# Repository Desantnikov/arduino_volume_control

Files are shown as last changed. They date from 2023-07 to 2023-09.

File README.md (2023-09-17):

<h1>Touchless PC volume controller arduino project.</h1>
<h2>
No need to touch stuff anymore. Adjust volume just by swinging your hand. 
</h2>

Basically you just place your hand inside this box and swing it up and down. And volume 
is changes according to your hand's Y position.  
Volume control and media play/pause will work only on windows 

<pre>
_____-
|
|
|
|
|
|
|
|
—   --
| ^  |
| 1* |
——----
</pre>

`1*` - distance sensor with measurement direction marked by ^ 

Main idea is to place a distance sensor inside the box. Distance sensor should 
be fixed on the bottom of the box. Distance measurements should be directed from box bottom to box top. 
Measurements happen several times per second. 
If currently measured distance equals to overall box height - it means that there
are no obstacles between the bottom and the top. But if measured distance is less than overall box 
height - it means that something is present in the box. And using measured distance we know it's
exact position on the Y coord. Then measurements values are sent to PC to adjust volume accordingly  

<h1>Version 1</h1> 
<h2>
Uses firmata protocol to fully control arduino from PC. 
No arduino code, all measurement values go directly to python script 
</h2> 

Sketch from examples of FirmataExpress arduino lib is uploaded on arduino. It fully implements firmata protocol
and gives ability to do all the shit you would want to do inside the arduino sketch. Allows not only setting 
pins HIGH or LOW, but also provides handy wrappers for many types of detectors. Everything is good 
except wired connection necessity.
Don't forget to set correct pins in the `/v1/constants.py`

Components used:
- Arduino nano
- US-015 ultrasonic distance sensor
<hr>

<h1>Version 2</h1>
<h2>
Uses better distance sensor and bluetooth module to send measurement results.
</h2>

Uses better distance sensor US-100, which supports UART mode and accepts commands instead
of setting and reading pins voltage directly. Also it has a built-in thermometer, which is not used in this
project. After first tests I could say that it works better than US-015.
Uses ZS-040 bluetooth module to send measurement results. Please note that before connecting it has to be
switched to the AT mode. To check if it's switched - open serial terminal and type "AT". And don't forget to set 
both CR and LF endlines. Official doc says that default connection password is "000000". In my case it was "1234".
All baudrates should be 9600, but in case of any issues you might try 38400.
Usually ZS-040 has a 'HC-06' bluetooth name.
Your PC should be paired with it to use it as a regular serial device using 'Serial over Bluetooth'.  

SW_520D tilt-switch sensor is used to track when user hit the controller. And if hit two 
times - plays/pauses what is currently playing
Curcuits schema can be found in /v2/circuits, `*.fxx` is a Fritzing applications format. Have much more 
components (like US-100 or ZA-40) than tinkercad, circuitIO and other webapp shit.   
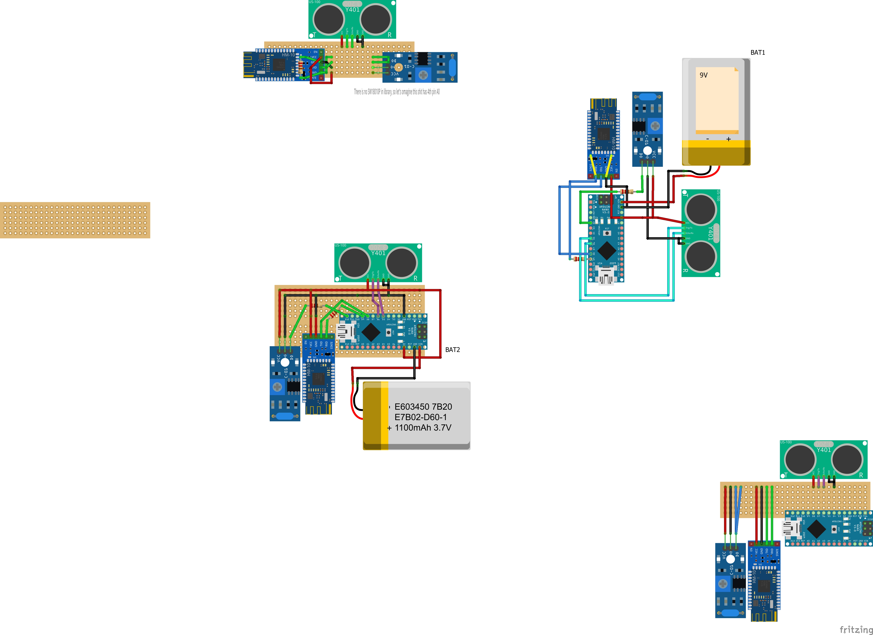
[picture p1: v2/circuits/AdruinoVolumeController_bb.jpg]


Lots of workarounds were used in python code and in arduino sketch. But these workarounds really improved 
the measurement process and made controlling PC with this stuff more or less smooth.

Python W/A's
1. When processing data from distance sensor - ignore fluctuations of less than 5% of volume
2. When registering doubleclick with vibration sensor 
   3. ignore vibros if they happened right after previous vibro - 
      usually that happens when sensor is not placed properly or instead of clicks user makes long pushes
   4. ignore doubleclick if second vibro happened too late after first vibro  
   5. ignore doubleclick if it happened too early after previous - same as 3th point

Similiar workarounds were made on the Arduino side.
Main question here is how this all will work when soldered. Maybe more workarounds will be needed. Or to rework 
using vibro sensor to read pin in a main loop instead of using interruptions

Components used:
- Arduino nano
- US-100 ultrasonic distance sensor
- ZS-040 bluetooth module
- SW18010P vibration sensor (initially took SW-520D, but I don't need a tilt sensor)
- 9v battery (to be replaced with 5v power supply, distance sensor goes crazy when 9v applied)

<h1>Version 2.1</h1>
<h3>
I have burnt ST_18010P vibro sensor during soldering and don't want to wait for a new one, so 
returning back to SW-520D vibration sensors.
</h3>
<p>
While ST_18010P was able to return both digital and analogue values, SW-520D   
</p>

Here is basic SW-520D connection circuit.
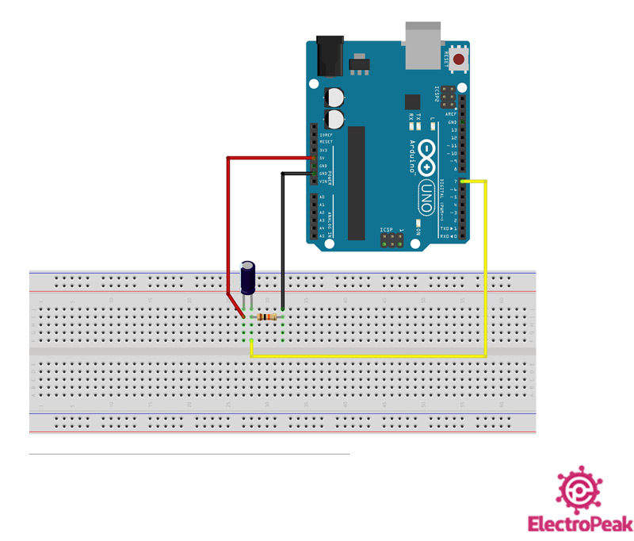
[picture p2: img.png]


Also analog reading when arduino is powered via USB from PC sucks. So currently 
I'll use only digital pins and postpone analog reading. Anyway, when powered from PC, 
it always returns either 800 or 0.  

Empirically I found out that if several such sensors are connected in 
parralel - they work like an OR clause.  You will have True (no vibration) when at
least one sensor returns true. 
When reading analog - you will have the biggest value from all sensors.
(it returns 0 when sensor is upside-down and 1023 when it's 
staying straight without movement).

And using several sensors at once helps to filter fake-positive cases. For example
when you make one tap - something about 15-20 events are triggered, and if you use 
interruptions then you have to make workarounds. Or sometimes you just have 
random fake-positive events.
On the other side, adding just one more sensor fixed problem with 15 events for one 
tap. And now double-tap could be caught almost perfectly and without any 
filtering/thresholds and other stuff.

<h1>Making and *.exe file</h1>
* make sure you have installed microsoft visual c++ 2015
* make sure you have installed gevent package
* execute `auto-py-to-exe`

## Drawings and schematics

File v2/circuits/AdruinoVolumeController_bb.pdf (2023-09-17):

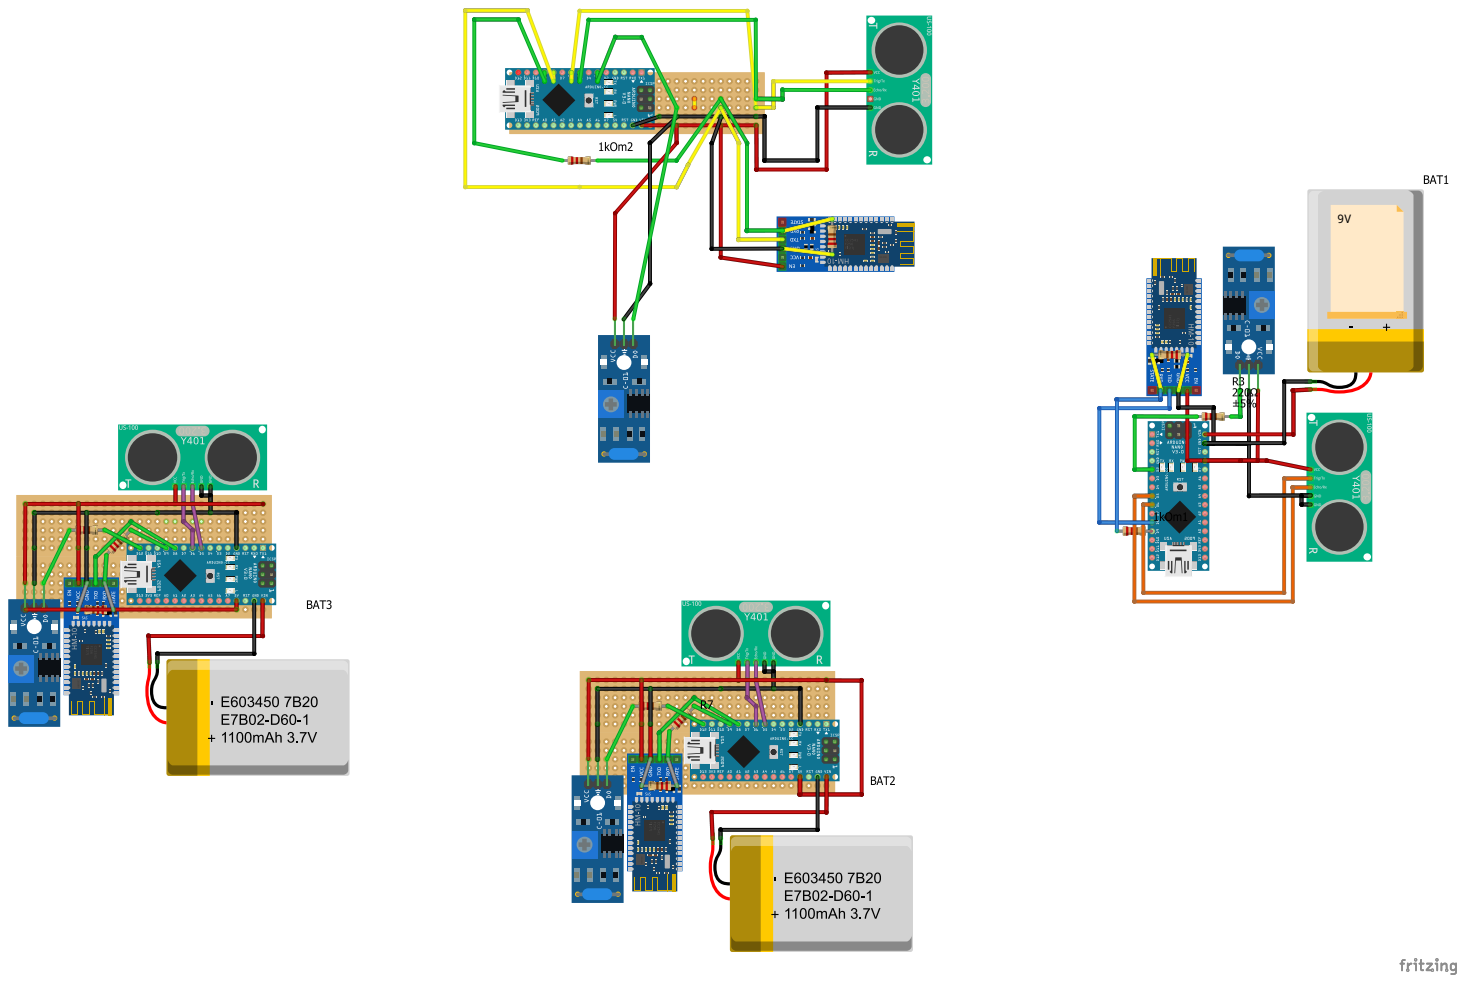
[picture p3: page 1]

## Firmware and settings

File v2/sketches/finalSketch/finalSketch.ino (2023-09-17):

#include <SoftwareSerial.h>;

// ultrasonic distance detector
const int US100_TX = 4;
const int US100_RX = 3;

// bluetooth module
const int ZS040_TX = 6;
const int ZS040_RX = 5;

//SW_520D vibration Sensor
//const int SW_520D_ANALOG_INPUT = A7;
const int SW_520D_DIGITAL_INPUT = 2;

int vibroSensorValue = 0;

SoftwareSerial detectorUS100(US100_RX, US100_TX);
SoftwareSerial bluetoothZS040(ZS040_RX, ZS040_TX);

unsigned int distanceRawFirstByte = 0;
unsigned int distanceRawSecondByte = 0;

unsigned int distanceMillimeters = 0, previousDistanceMillimeters = 0;

// function sends string via BT module byte by byte
void sendStringBluetooth(String stringToSend) {
  Serial.print("Sending data via BT: " + stringToSend + "\r\n");

  for (int i = 0; i < stringToSend.length(); i++) {
    bluetoothZS040.write(stringToSend[i]);
  }
  // delay(30);
}

int getDistance() {  // to measure distance in UART mode it's needed to:
    detectorUS100.flush();  // clear buffer
    detectorUS100.write(0x55);  // send command to measure distance

    delay(50);  // setting lower than 100 cause shitty measurements

    distanceRawFirstByte = detectorUS100.read();
    distanceRawSecondByte  = detectorUS100.read();

    distanceMillimeters = distanceRawFirstByte * 256 + distanceRawSecondByte;

    return distanceMillimeters;
}

void processDistance(int distanceMillimeters, int previousDistanceMillimeters) {
    // Serial.print("Distance: ");
    // Serial.print(distanceMillimeters);
    if (distanceMillimeters == previousDistanceMillimeters)
    {
// //
      // Serial.print("; Difference is less than 5 millimeters, ignore \r\n");
      return;
    }

    if((distanceMillimeters > 45) && (distanceMillimeters < 350))  // limits should align with limits from constants.py
    {
      sendStringBluetooth("Distance: " + String(distanceMillimeters) + "\r\n");
    }

}

void setup() {
 Serial.begin(9600);
 Serial.write("STARTED");

  bluetoothZS040.begin(9600);  // BT module
  detectorUS100.begin(9600);  // distance
  
  // pinMode(SW_18010P_ANALOG, INPUT);  // vibro
 pinMode(SW_520D_DIGITAL_INPUT, INPUT);  // vibro
}

void loop()
{

  vibroSensorValue = digitalRead(SW_520D_DIGITAL_INPUT);
// averageVibroSensorValue

   if (vibroSensorValue == LOW) {
    // if (vibroSensorValue == 0) {
      Serial.println("Vibro sensor triggered");
       sendStringBluetooth("Vibro: " + String(vibroSensorValue) + "\r\n");
     }
   delay(50);
  // }
  
  
 previousDistanceMillimeters = distanceMillimeters;
 distanceMillimeters = getDistance();
//
  processDistance(distanceMillimeters, previousDistanceMillimeters);

}

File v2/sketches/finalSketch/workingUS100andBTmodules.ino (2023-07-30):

#include <SoftwareSerial.h>;

// ultrasonic distance detector
const int US100_TX = 2;
const int US100_RX = 3;

// bluetooth module
const int ZS040_TX = 9;
const int ZS040_RX = 8;

SoftwareSerial detectorUS100(US100_RX, US100_TX);
SoftwareSerial bluetoothZS040(ZS040_RX, ZS040_TX);

unsigned int distanceRawFirstByte = 0;
unsigned int distanceRawSecondByte = 0;

unsigned int distanceMillimeters = 0;

String distanceString;


void setup() {
  Serial.begin(9600);
  bluetoothZS040.begin(9600);
  detectorUS100.begin(9600);
}
 
void loop() {
  detectorUS100.flush(); 
  detectorUS100.write(0x55);  // send command to measure distance

  delay(30);  // setting below this value cause shit

  if(detectorUS100.available() >= 2) 
  {
    distanceRawFirstByte = detectorUS100.read();  
    distanceRawSecondByte  = detectorUS100.read();

    distanceMillimeters  = distanceRawFirstByte * 256 + distanceRawSecondByte; 

    if((distanceMillimeters > 1) && (distanceMillimeters < 10000)) 
    {
      distanceString = "Distance: " + String(distanceMillimeters) + "\r\n";
      Serial.print(distanceString);

      for (int i = 0; i < distanceString.length(); i++)
      {
        bluetoothZS040.write(distanceString[i]);
      }
    }

  }

}

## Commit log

2023-07-14 initial, ultrasonic detector shows valid distance
2023-07-14 example with threading and working led
2023-07-14 example working led without threading
2023-07-30 Added new device version, refactored old, added readme
2023-08-10 added SW_520D tilt sensor and made it work; code has to be refactored
2023-08-11 changed vibration sensor
2023-09-17 I have burnt ST_18010P during soldering and don't want to wait for a new one, so returning back to using SW-520D vibration sensors
    [AdruinoVolumeController.fzz]
